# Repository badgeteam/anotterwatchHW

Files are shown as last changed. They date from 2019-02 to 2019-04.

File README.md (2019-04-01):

# AnOtter_Watch

ESP32 driven smart watch with 14-Bit, 2 MSPS Dual Channel scope and component tester.

Back AnOtter_Watch back

[Schematics](/schematics_V1.1/anotterwatch.pdf) read more on the [Wiki](https://wiki.badge.team/AnOtter_Watch)

Designed in KiCad

## Current project status

Prototype d0a3733 ordered

[Gerber files](/gerber_V1.0.zip)

Front AnOtter_Watch front

## V1.1

# Errors

 - [ ] ESP-Pico-D4 foorpint
 - [ ] Display cutout
 - [ ] TCA9535 GND level is ~0.5V when USB is unplugged
 - [ ] WS2812 leds are not working when USB is plugged
 - [ ] Button down can only be pressed when the battery is connected
 
# Tested
  
  - PMIC
  - Charging
  - WS2812
  - Display
  - I2C switch
  - USB-Plug
  - CH341C
  - Button

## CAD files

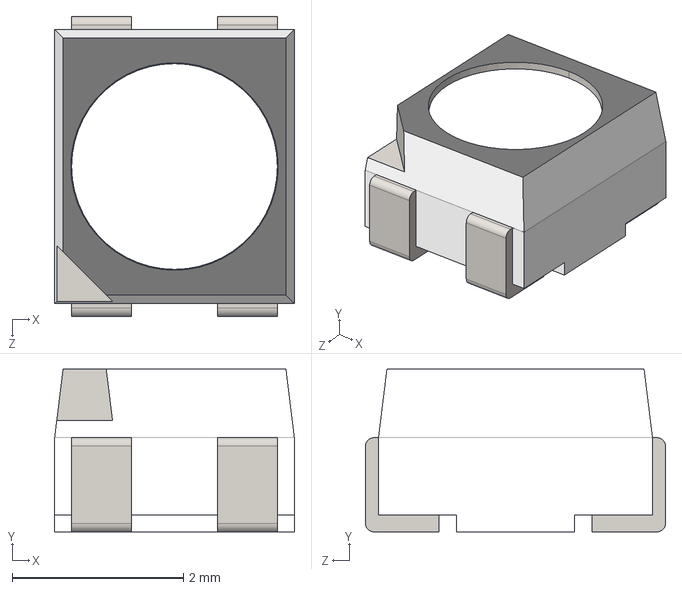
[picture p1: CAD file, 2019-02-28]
3D_models/User Library-ASMB-MTB0-0A3A2.step
2.80 x 1.90 x 3.50 mm

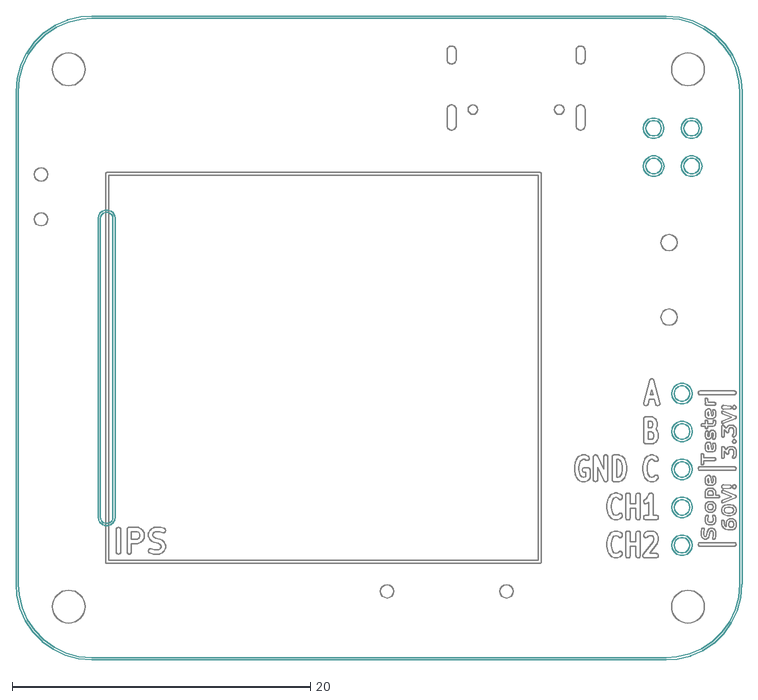
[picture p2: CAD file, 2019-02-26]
anotterwatch_art.dxf
48.7 x 43.2

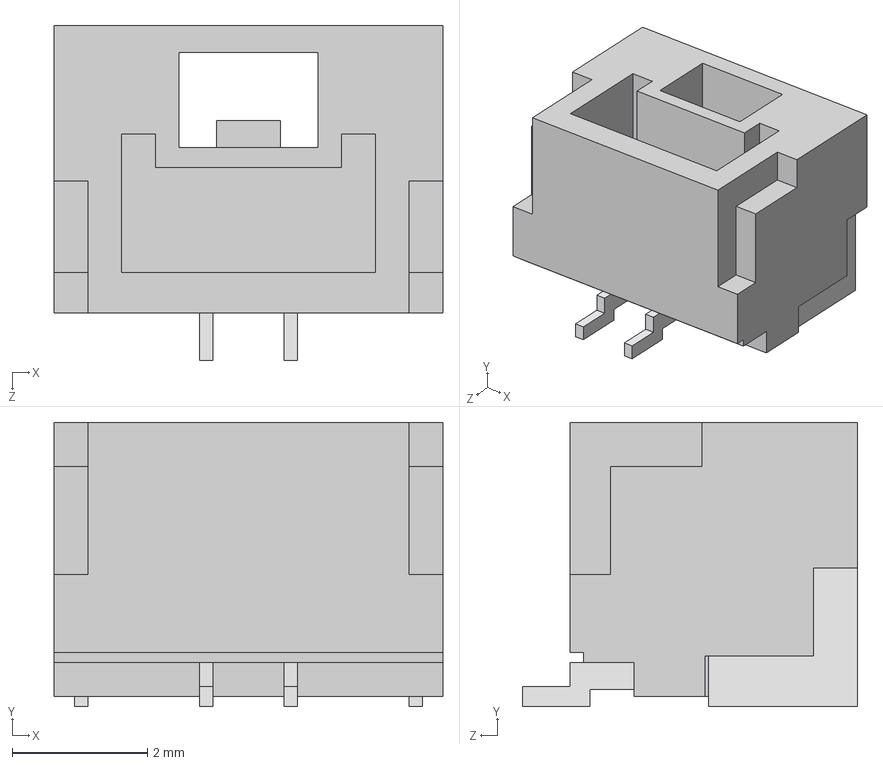
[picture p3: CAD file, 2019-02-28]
3D_models/BM02B-GHS-TBT.STEP
5.75 x 4.20 x 4.95 mm

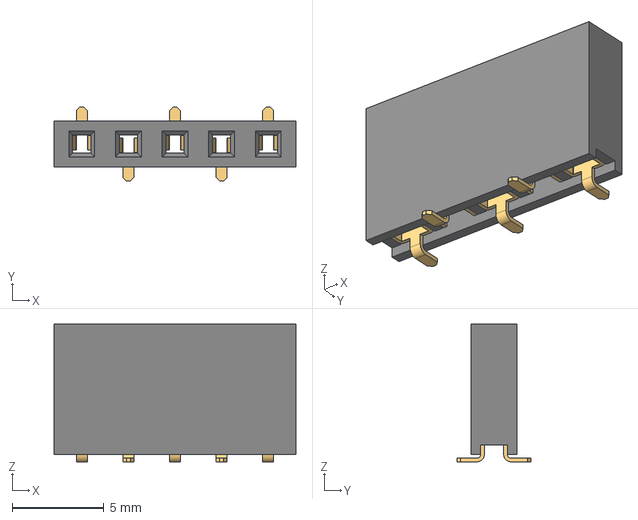
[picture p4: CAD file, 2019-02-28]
3D_models/61000511921 (rev1).stp
13.2 x 4.05 x 7.51 mm
6100051xx21
6100xx1xx21_PIN x 5

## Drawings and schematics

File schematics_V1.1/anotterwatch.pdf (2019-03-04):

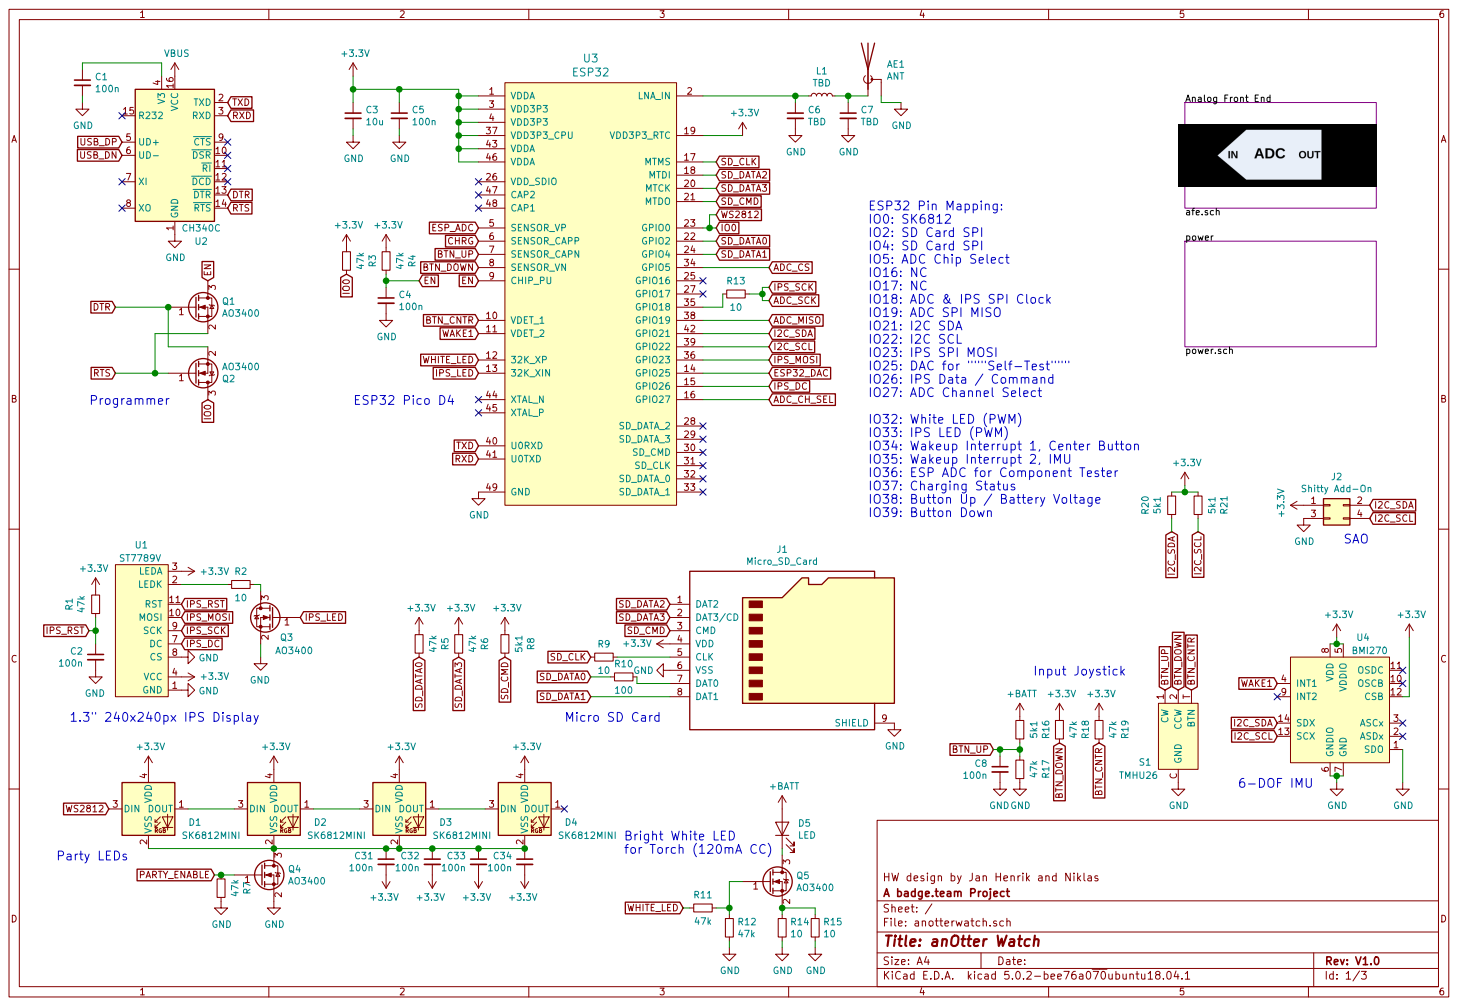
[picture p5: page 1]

1 DSR 10 RI 11 DCD 12 DTR 13 RTS 14 R232 15 VCC 16 TXD 2 RXD 3 V3

4 UD+ 5 UD- 6 XI 7 XO 8 CTS 9 U2 CH340C GND

ESP32 Pin Mapping:
IO2: SD Card SPI
IO4: SD Card SPI
IO5: ADC Chip Select
IO18: ADC & IPS SPI Clock
IO19: ADC SPI MISO
IO21: I2C SDA
IO22: I2C SCL
IO23: IPS SPI MOSI
IO25: DAC for """Self-Test"""
IO26: IPS Data / Command
IO27: ADC Channel Select
IO32: White LED (PWM)
IO33: IPS LED (PWM)
IO34: Wakeup Interrupt 1, Center Button
IO35: Wakeup Interrupt 2, IMU
IO36: ESP ADC for Component Tester
IO37: Charging Status
IO38: Button Up / Battery Voltage

HW design by Jan Henrik and Niklas D5

File: anotterwatch.sch Sheet: / A badge.team Project

Id: 1/3 Title: anOtter Watch

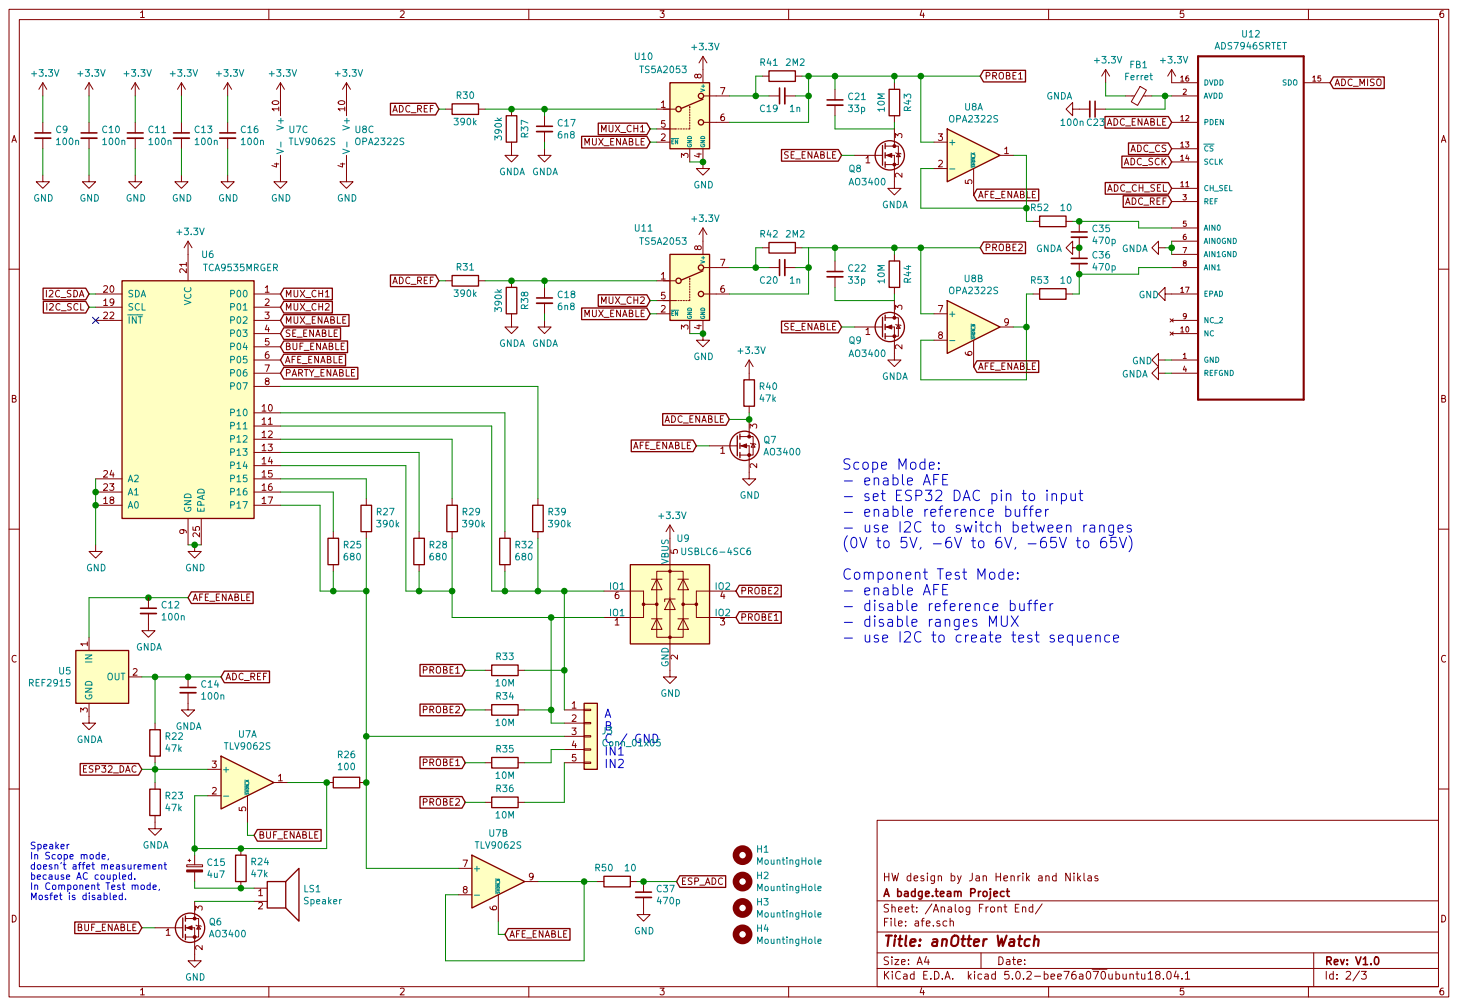
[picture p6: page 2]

- enable AFE
- set ESP32 DAC pin to input
- enable reference buffer
- use I2C to switch between ranges
Component Test Mode:
- disable reference buffer
- disable ranges MUX
- use I2C to create test sequence

47k Speaker
In Scope mode, doesn't affet measurement because AC coupled.

HW design by Jan Henrik and Niklas
A badge.team Project
File: afe.sch Sheet: /Analog Front End/
Id: 2/3 Title: anOtter Watch

In Component Test mode, Mosfet is disabled.

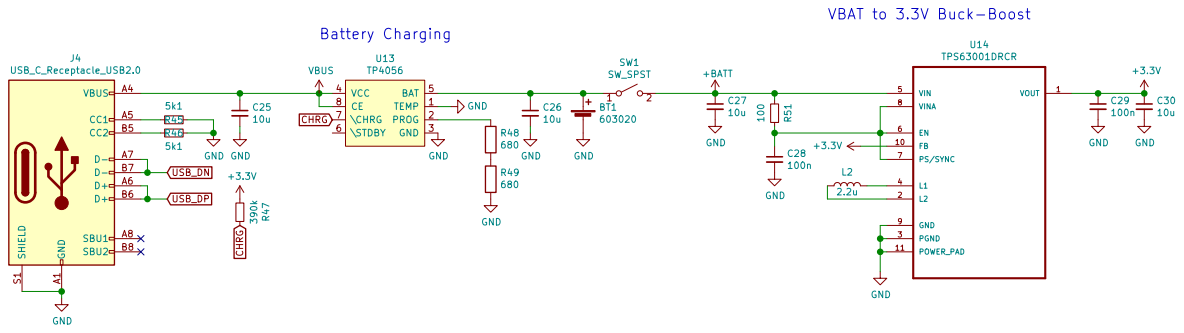
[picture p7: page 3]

A badge.team Project
Sheet: /power/
File: power.sch
Id: 3/3 Title: anOtter Watch

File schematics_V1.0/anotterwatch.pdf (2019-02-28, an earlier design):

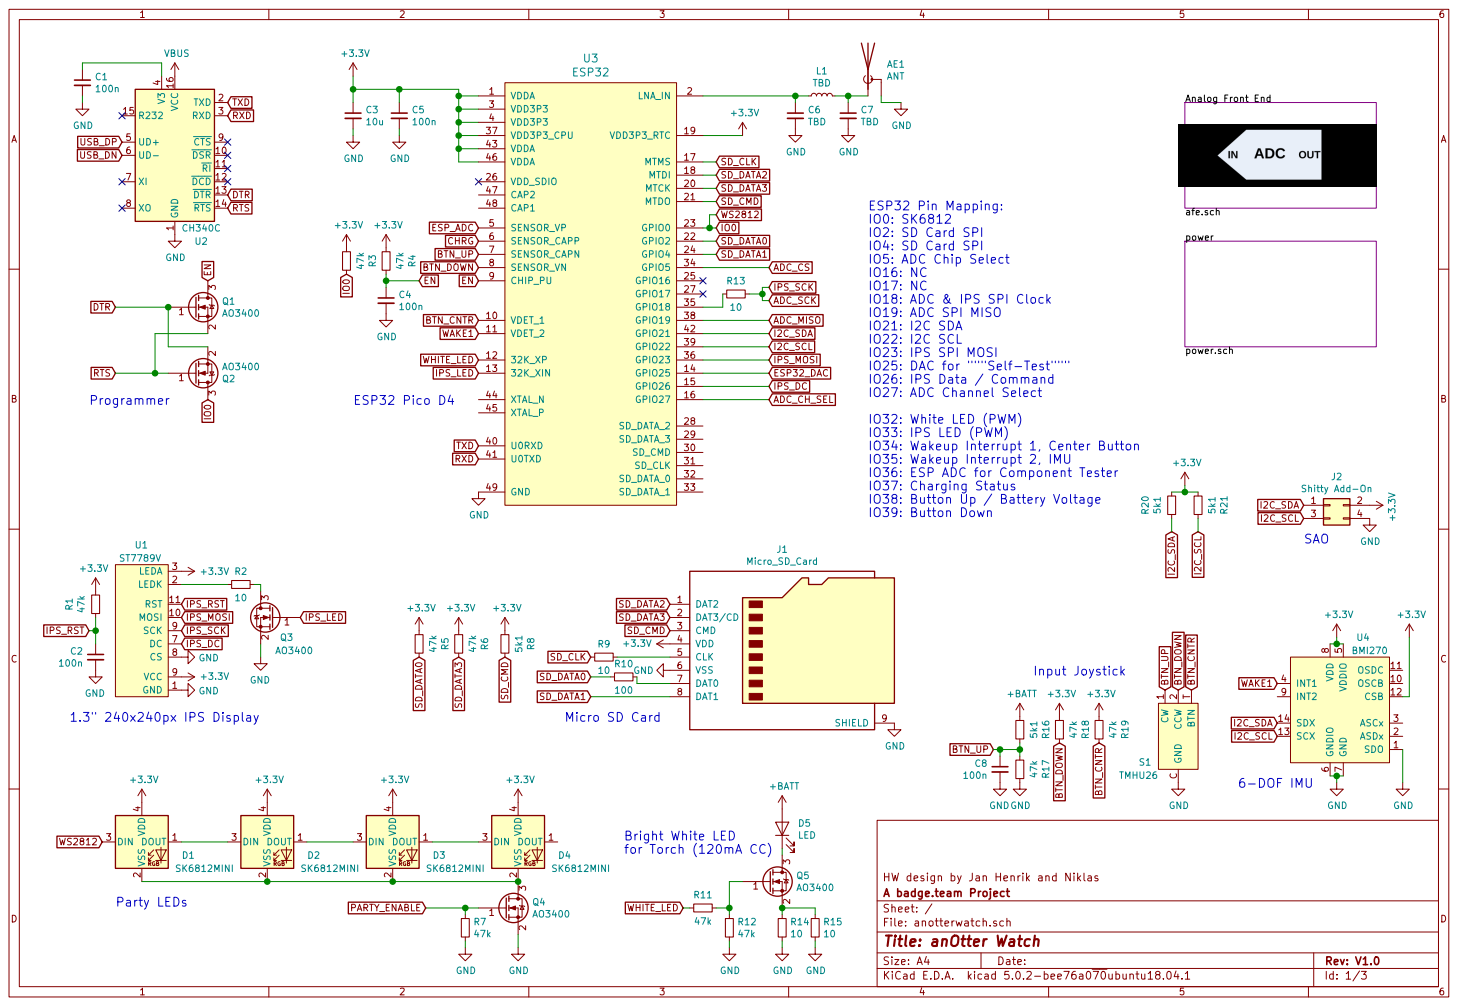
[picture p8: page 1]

1 DSR 10 RI 11 DCD 12 DTR 13 RTS 14 R232 15 VCC 16 TXD 2 RXD 3 V3

4 UD+ 5 UD- 6 XI 7 XO 8 CTS 9 U2 CH340C GND

ESP32 Pin Mapping:
IO2: SD Card SPI
IO4: SD Card SPI
IO5: ADC Chip Select
IO18: ADC & IPS SPI Clock
IO19: ADC SPI MISO
IO21: I2C SDA
IO22: I2C SCL
IO23: IPS SPI MOSI
IO25: DAC for """Self-Test"""
IO26: IPS Data / Command
IO27: ADC Channel Select
IO32: White LED (PWM)
IO33: IPS LED (PWM)
IO34: Wakeup Interrupt 1, Center Button
IO35: Wakeup Interrupt 2, IMU
IO36: ESP ADC for Component Tester
IO37: Charging Status
IO38: Button Up / Battery Voltage

HW design by Jan Henrik and Niklas D5

File: anotterwatch.sch Sheet: / A badge.team Project

Id: 1/3 Title: anOtter Watch

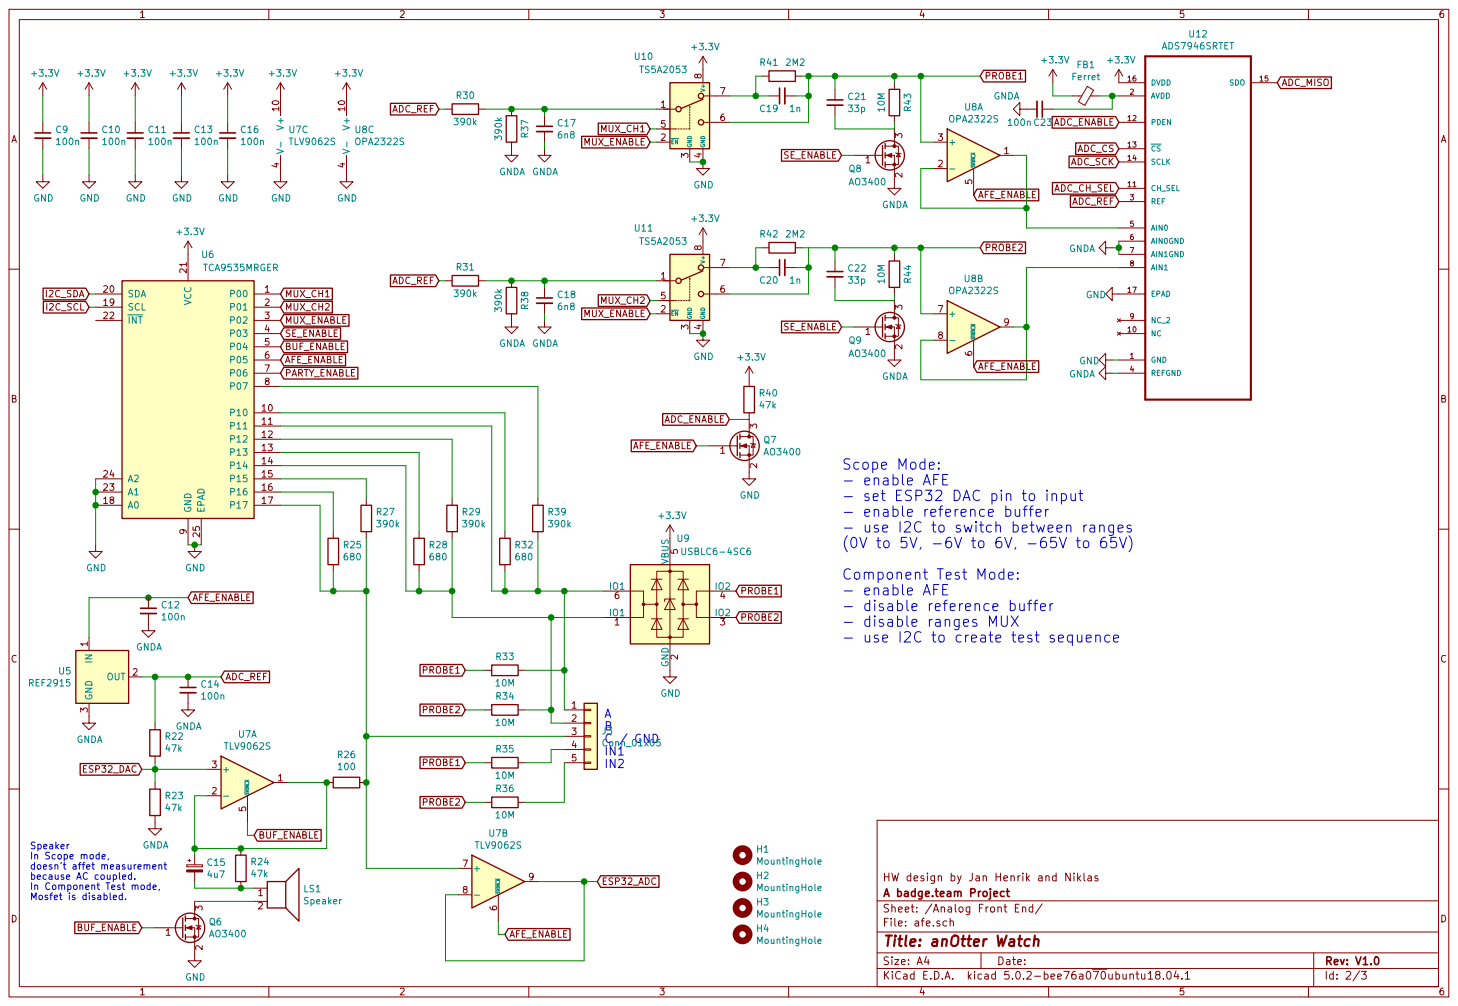
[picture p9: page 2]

- enable AFE
- set ESP32 DAC pin to input
- enable reference buffer
- use I2C to switch between ranges
Component Test Mode:
- disable reference buffer
- disable ranges MUX
- use I2C to create test sequence

47k Speaker
In Scope mode, doesn't affet measurement because AC coupled.

HW design by Jan Henrik and Niklas
A badge.team Project
File: afe.sch Sheet: /Analog Front End/
Id: 2/3 Title: anOtter Watch

In Component Test mode, Mosfet is disabled.

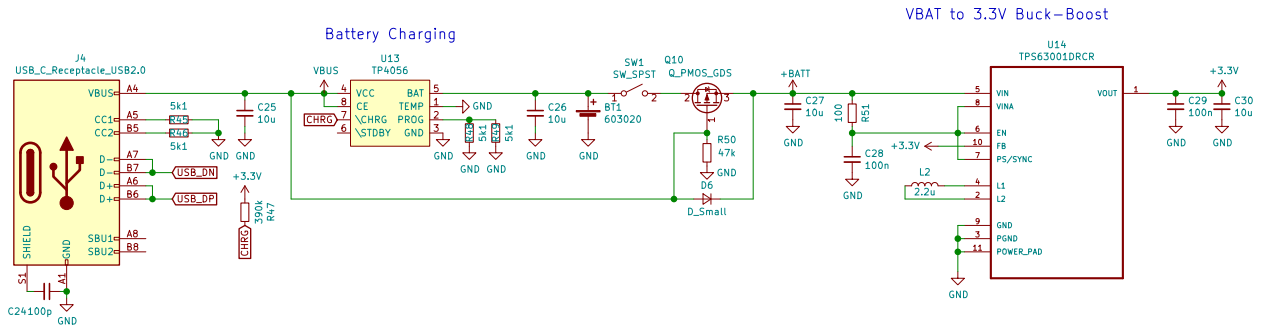
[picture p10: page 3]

A badge.team Project
Sheet: /power/
File: power.sch
Id: 3/3 Title: anOtter Watch

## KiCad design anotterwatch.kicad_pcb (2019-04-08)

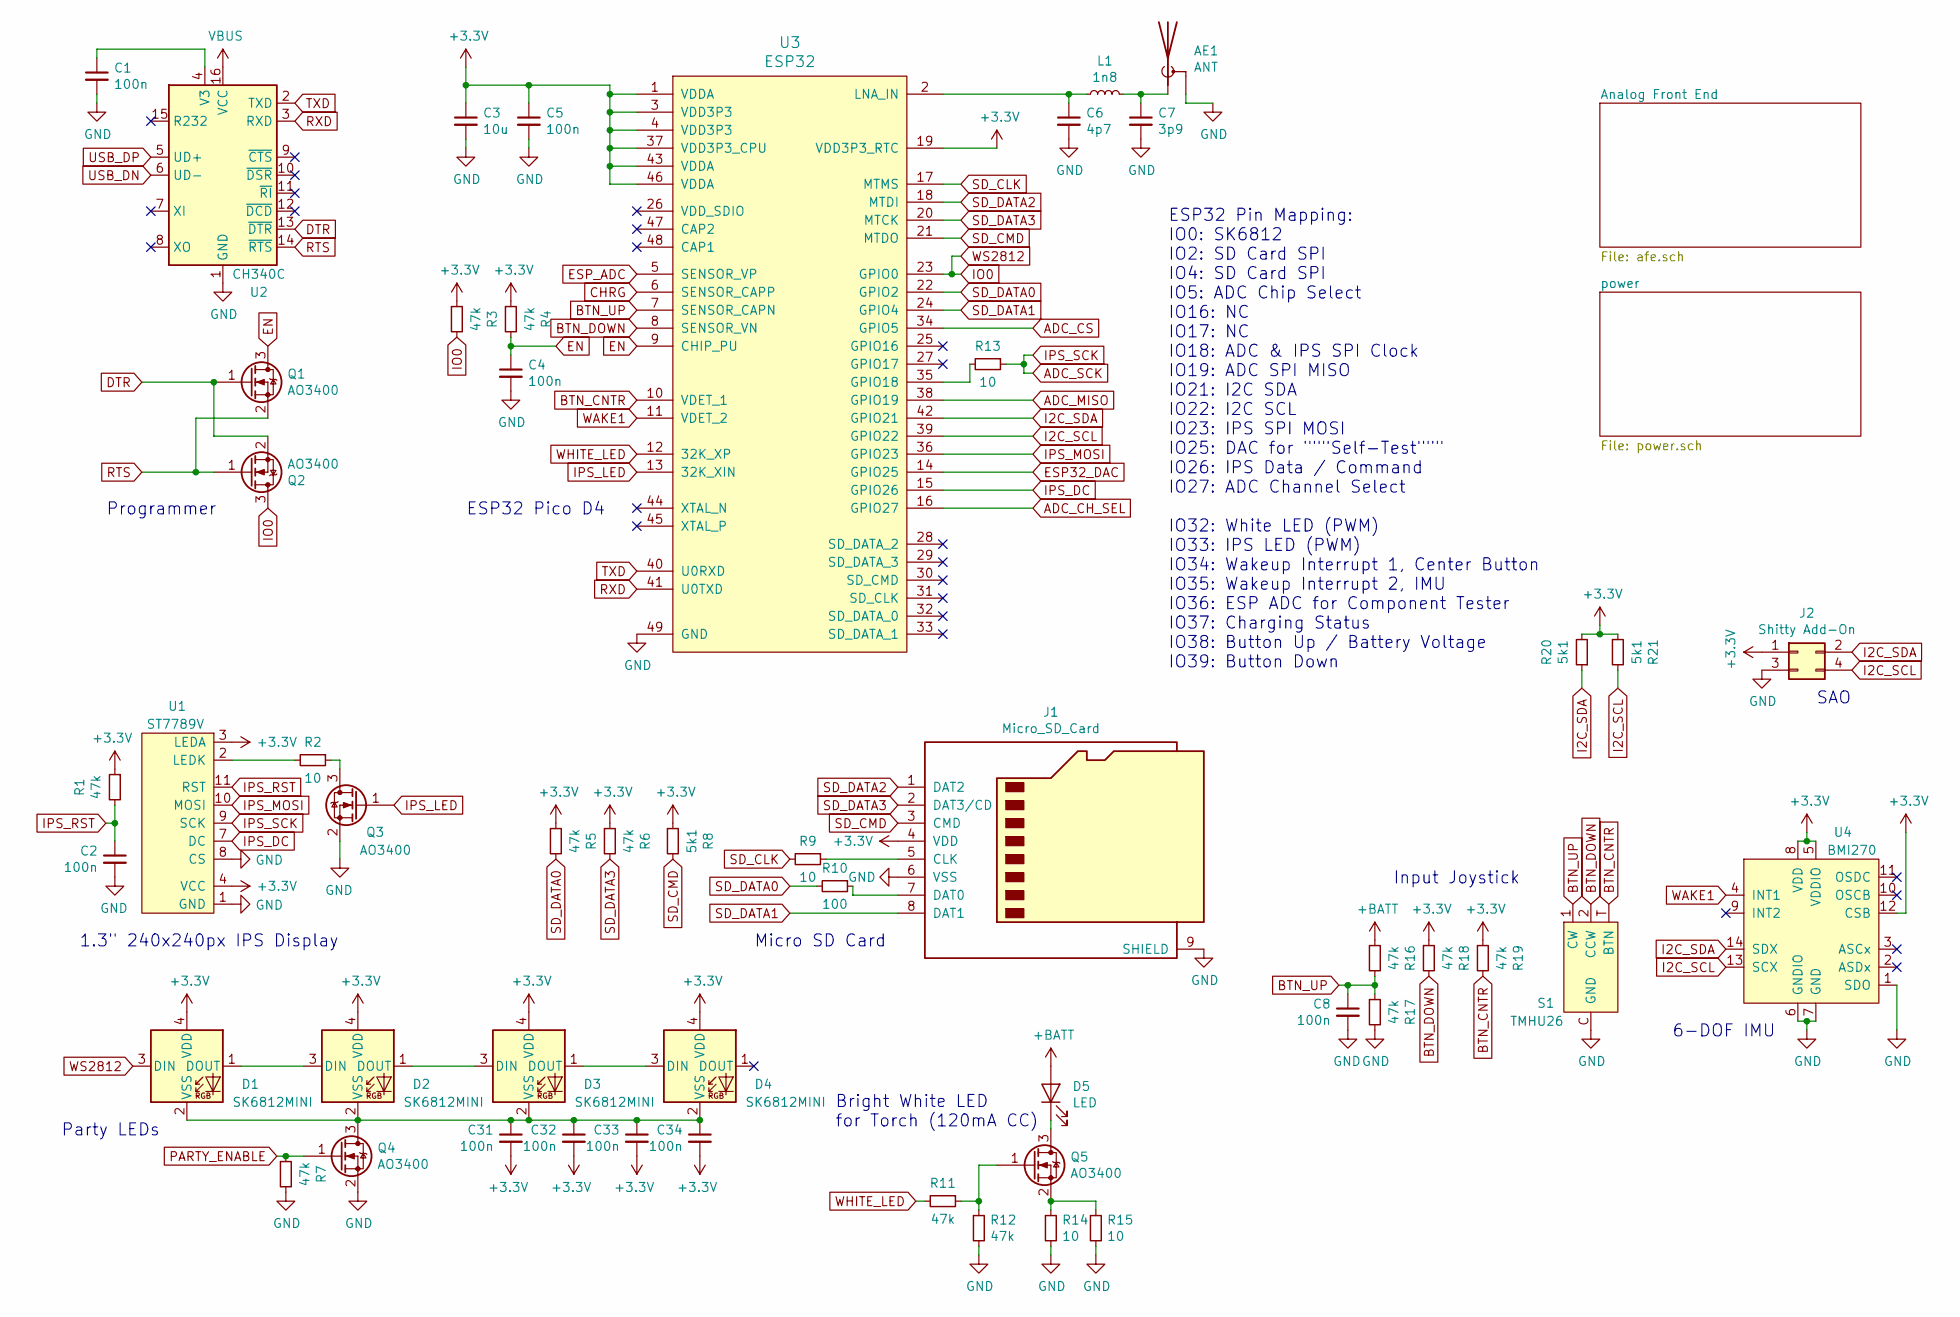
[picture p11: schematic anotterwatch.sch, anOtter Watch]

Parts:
AE1: ANT; Texas_SWRA117D_2.4GHz_Left
C1, C2, C4, C5, C8, C31, C32, C33, C34: 100n; C_0402_1005Metric
C3: 10u; C_0603_1608Metric
C6: 4p7; C_0402_1005Metric
C7: 3p9; C_0402_1005Metric
D1, D2, D3, D4: SK6812MINI; LED_SK6812MINI_PLCC4_3.5x3.5mm_P1.75mm
D5: LED; RZX-S020CCW-0.4T
J1: Micro_SD_Card; SUNTECH_ST-TF-003A
J2: Shitty Add-On; PinSocket_2x02_P2.54mm_Vertical_SMD
L1: 1n8; L_0603_1608Metric
Q1, Q2, Q3, Q4, Q5: AO3400; SOT-23
R1, R3, R4, R5, R6, R7, R11, R12, R16, R17, R18, R19: 47k; R_0402_1005Metric
R2, R9, R13, R14, R15: 10; R_0603_1608Metric
R8, R20, R21: 5k1; R_0402_1005Metric
R10: 100; R_0402_1005Metric
S1: TMHU26
U1: ST7789V
U2: CH340C; SOIC-16_3.9x9.9mm_P1.27mm
U3: ESP32; QFN-48-1EP_7x7mm_P0.5mm_EP5.3x5.3mm
U4: BMI270

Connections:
+3V3: C3.1, C5.1, C31.2, C32.2, C33.2, C34.2, D1.4 (VDD), D2.4 (VDD), D3.4 (VDD), D4.4 (VDD), J1.4 (VDD), J2.1, R1.1, R3.1, R4.1, R5.1, R6.1, R8.1, R18.1, R19.1, R20.2, R21.1, U1.3 (LEDA), U1.4 (VCC), U3.1 (VDDA), U3.3 (VDD3P3), U3.4 (VDD3P3), U3.19 (VDD3P3_RTC), U3.37 (VDD3P3_CPU), U3.43 (VDDA), U3.46 (VDDA), U4.5 (VDDIO), U4.8 (VDD), U4.12 (CSB); also elsewhere on the board
ADC_CH_SEL: U3.16 (GPIO27); also elsewhere on the board
ADC_CS: U3.34 (GPIO5); also elsewhere on the board
ADC_MISO: U3.38 (GPIO19); also elsewhere on the board
ADC_SCK: R13.1, U1.9 (SCK); also elsewhere on the board
BTN_CNTR: R19.2, S1.T (BTN), U3.10 (VDET_1)
BTN_DOWN: R18.2, S1.2 (CCW), U3.8 (SENSOR_VN)
BTN_UP: C8.1, R16.2, R17.1, S1.1 (CW), U3.7 (SENSOR_CAPN)
CHRG: U3.6 (SENSOR_CAPP); also elsewhere on the board
DTR: Q1.1 (G), Q2.2 (S), U2.13 (~DTR)
EN: C4.1, Q1.3 (D), R4.2, U3.9 (CHIP_PU)
ESP32_DAC: U3.14 (GPIO25); also elsewhere on the board
ESP_ADC: U3.5 (SENSOR_VP); also elsewhere on the board
GND: AE1.2 (Shield), C1.2, C2.2, C3.2, C4.2, C5.2, C6.2, C7.2, C8.2, J1.6 (VSS), J1.9 (SHIELD), J2.3, Q3.2 (S), Q4.2 (S), R7.2, R12.2, R14.2, R15.2, R17.2, S1.C (GND), U1.1 (GND), U1.5 (GND), U1.6 (GND), U1.8 (CS), U1.12, U2.1 (GND), U3.49 (GND), U4.1 (SDO), U4.6 (GNDIO), U4.7 (GND); also elsewhere on the board
I2C_SCL: J2.4, R21.2, U3.39 (GPIO22), U4.13 (SCX); also elsewhere on the board
I2C_SDA: J2.2, R20.1, U3.42 (GPIO21), U4.14 (SDX); also elsewhere on the board
IO0: D1.3 (DIN), Q2.3 (D), R3.2, U3.23 (GPIO0)
IPS_DC: U1.7 (DC), U3.15 (GPIO26)
IPS_LED: Q3.1 (G), U3.13 (32K_XIN)
IPS_MOSI: U1.10 (MOSI), U3.36 (GPIO23)
IPS_RST: C2.1, R1.2, U1.11 (RST)
unnamed: AE1.1 (A), C7.1, L1.2
unnamed: C1.1, U2.4 (V3)
unnamed: C6.1, L1.1, U3.2 (LNA_IN)
unnamed: C31.1, C32.1, C33.1, C34.1, D1.2 (VSS), D2.2 (VSS), D3.2 (VSS), D4.2 (VSS), Q4.3 (D)
unnamed: D1.1 (DOUT), D2.3 (DIN)
unnamed: D2.1 (DOUT), D3.3 (DIN)
unnamed: D3.1 (DOUT), D4.3 (DIN)
unnamed: J1.5 (CLK), R9.1
unnamed: J1.7 (DAT0), R10.1
unnamed: Q3.3 (D), R2.1
unnamed: Q5.1 (G), R11.1, R12.1
unnamed: Q5.2 (S), R14.1, R15.1
unnamed: R2.2, U1.2 (LEDK)
unnamed: R13.2, U3.35 (GPIO18)
PARTY_ENABLE: Q4.1 (G), R7.1; also elsewhere on the board
RTS: Q1.2 (S), Q2.1 (G), U2.14 (~RTS)
RXD: U2.3 (RXD), U3.41 (U0TXD)
SD_CLK: R9.2, U3.17 (MTMS)
SD_CMD: J1.3 (CMD), R8.2, U3.21 (MTDO)
SD_DATA0: R5.2, R10.2, U3.22 (GPIO2)
SD_DATA1: J1.8 (DAT1), U3.24 (GPIO4)
SD_DATA2: J1.1 (DAT2), U3.18 (MTDI)
SD_DATA3: J1.2 (DAT3/CD), R6.2, U3.20 (MTCK)
TXD: U2.2 (TXD), U3.40 (U0RXD)
USB_DN: U2.6 (UD-); also elsewhere on the board
USB_DP: U2.5 (UD+); also elsewhere on the board
VBUS: U2.16 (VCC); also elsewhere on the board
WAKE1: U3.11 (VDET_2), U4.4 (INT1)
WHITE_LED: R11.2, U3.12 (32K_XP)

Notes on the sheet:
ESP32 Pin Mapping: IO0: SK6812 IO2: SD Card SPI IO4: SD Card SPI IO5: ADC Chip Select IO16: NC IO17: NC IO18: ADC & IPS SPI Clock IO19: ADC SPI MISO IO21: I2C SDA IO22: I2C SCL IO23: IPS SPI MOSI IO25: DAC for """Self-Test""" IO26: IPS Data / Command IO27: ADC Channel Select IO32: White LED (PWM) I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
Programmer
1.3" 240x240px IPS Display
Party LEDs
Bright White LED for Torch (120mA CC)
Micro SD Card
Input Joystick
6-DOF IMU
SAO
ESP32 Pico D4

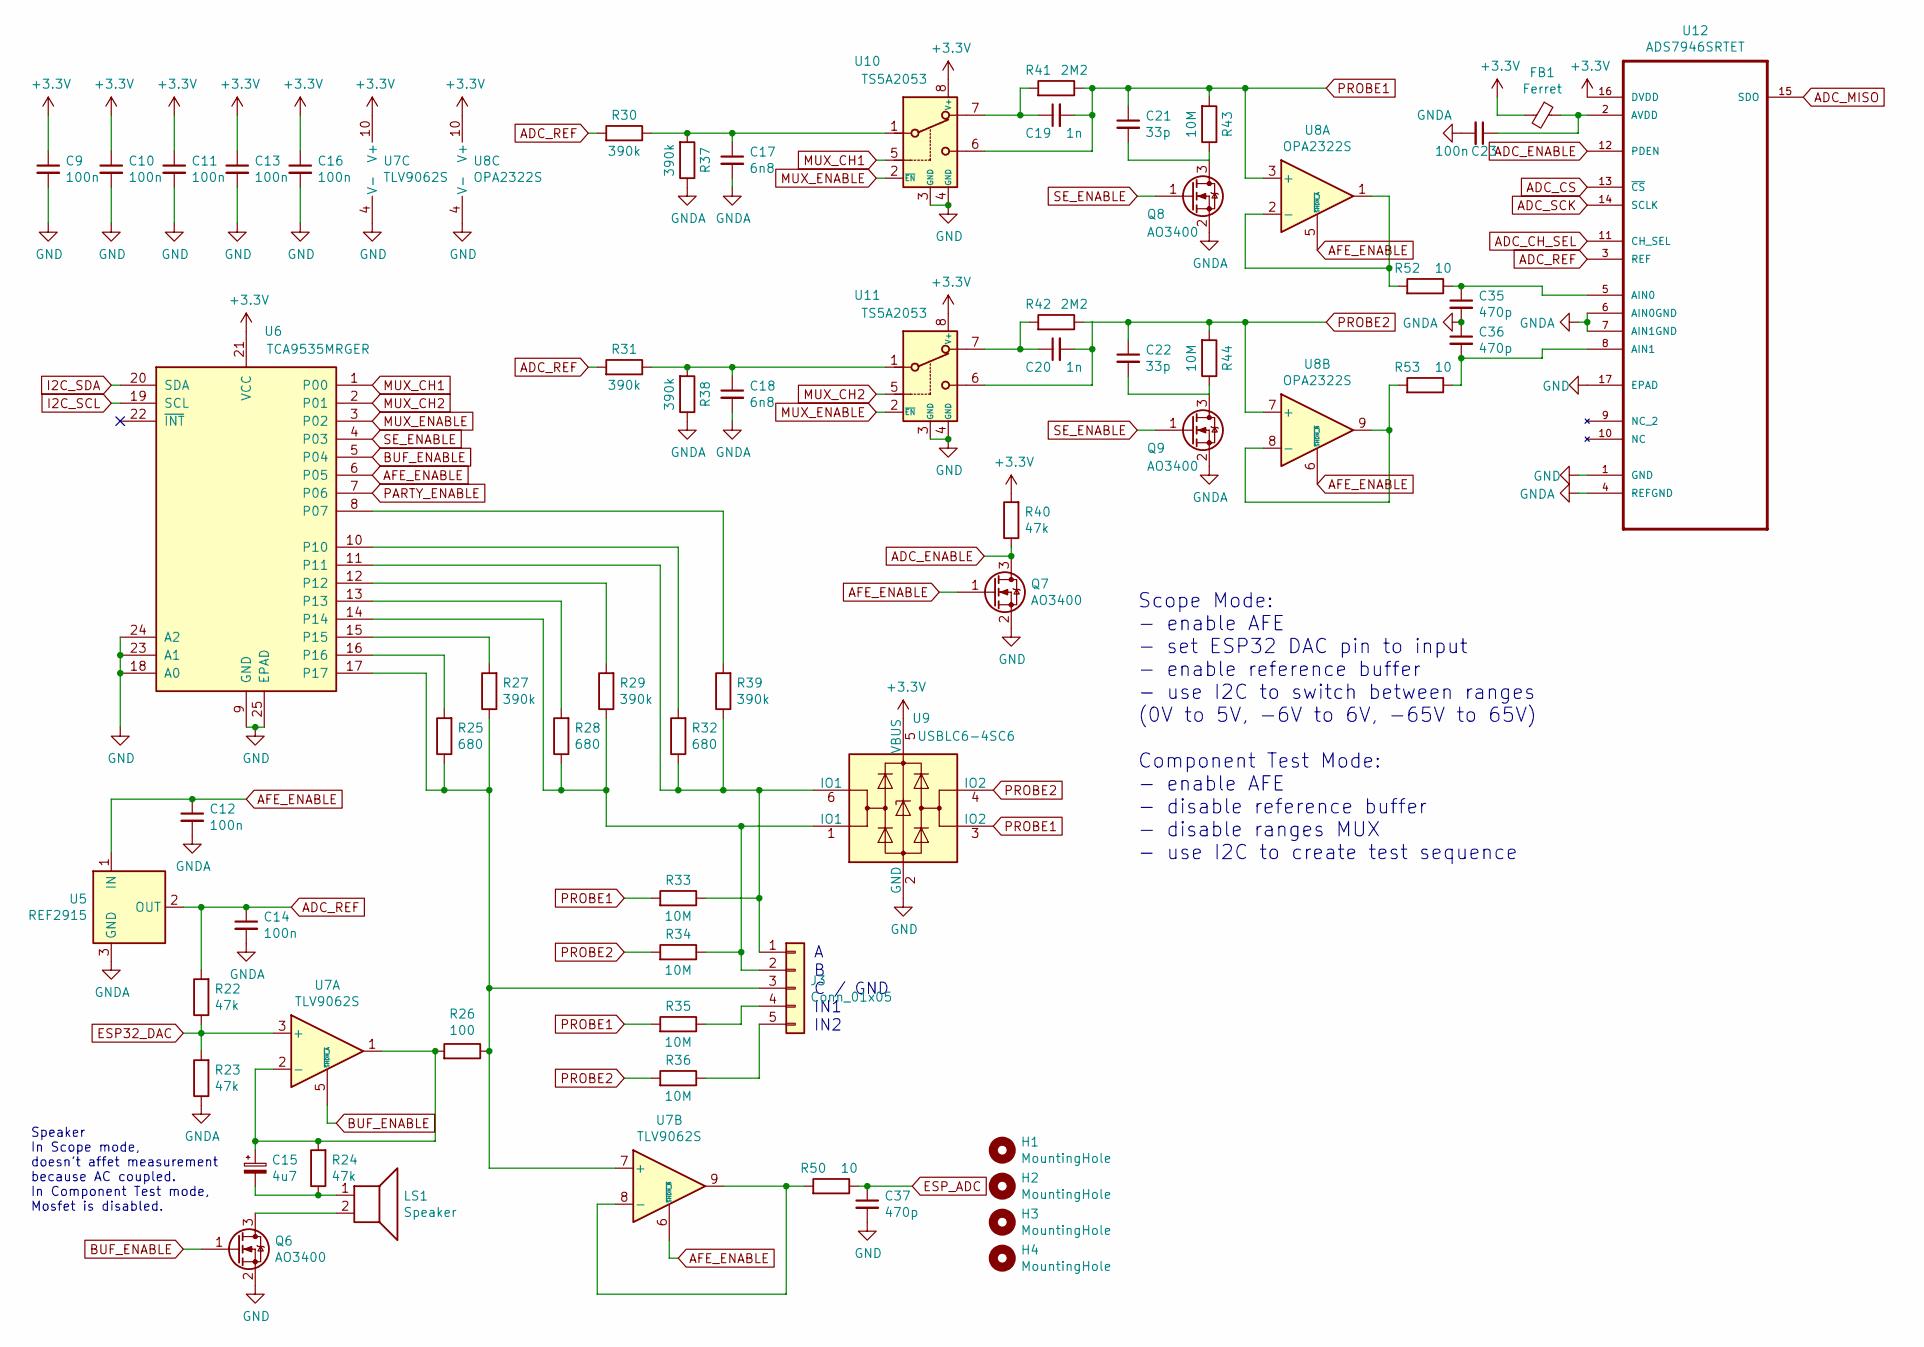
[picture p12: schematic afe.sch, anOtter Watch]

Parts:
C9, C10, C11, C12, C13, C14, C16: 100n; C_0402_1005Metric
C15: 4u7; C_0603_1608Metric
C17, C18: 6n8; C_0402_1005Metric
C19, C20: 1n; C_0402_1005Metric
C21, C22: 33p; C_0402_1005Metric
C23: 100n; C_0603_1608Metric
C35, C36, C37: 470p; C_0402_1005Metric
FB1: Ferret; L_0603_1608Metric
H1, H2, H3, H4: MountingHole; MountingHole_2.2mm_M2
J3: Conn_01x05; PinHeader_1x05_P2.54mm_Vertical_SMD_Pin1Left
LS1: Speaker; Molex_KK-254_AE-6410-02A_1x02_P2.54mm_Vertical
Q6, Q7, Q8, Q9: AO3400; SOT-23
R22, R23, R24, R40: 47k; R_0402_1005Metric
R25, R28, R32: 680; R_0402_1005Metric
R26: 100; R_0402_1005Metric
R27, R29, R30, R31, R37, R38, R39: 390k; R_0402_1005Metric
R33, R34, R35, R36: 10M; R_0603_1608Metric
R41, R42: 2M2; R_0402_1005Metric
R43, R44: 10M; R_0402_1005Metric
R50, R52, R53: 10; R_0603_1608Metric
U5: REF2915; SOT-23
U6: TCA9535MRGER; QFN-24-1EP_4x4mm_P0.5mm_EP2.6x2.6mm
U7: TLV9062S; VSSOP-10
U8: OPA2322S; VSSOP-10
U9: USBLC6-4SC6; SOT-23-6
U10, U11: TS5A2053; VSSOP-8_2.4x2.1mm_P0.5mm
U12: ADS7946SRTET; QFN-16-1EP_3x3mm_P0.5mm_EP1.8x1.8mm

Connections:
+3V3: C9.1, C10.1, C11.1, C13.1, C16.1, FB1.2, R40.2, U6.21 (VCC), U7.10 (V+), U8.10 (V+), U9.5 (VBUS), U10.8 (V+), U11.8 (V+), U12.16 (DVDD); also elsewhere on the board
ADC_CH_SEL: U12.11 (CH_SEL); also elsewhere on the board
ADC_CS: U12.13 (~CS~); also elsewhere on the board
ADC_ENABLE: Q7.3 (D), R40.1, U12.12 (PDEN)
ADC_MISO: U12.15 (SDO); also elsewhere on the board
ADC_REF: C14.1, R22.2, R30.2, R31.2, U5.2 (OUT), U12.3 (REF)
ADC_SCK: U12.14 (SCLK); also elsewhere on the board
AFE_ENABLE: C12.1, Q7.1 (G), U5.1 (IN), U6.6 (P05), U7.6 (~SHDN_B), U8.5 (~SHDN_A), U8.6 (~SHDN_B)
BUF_ENABLE: Q6.1 (G), U6.5 (P04), U7.5 (~SHDN_A)
ESP32_DAC: R22.1, R23.2, U7.3 (+); also elsewhere on the board
ESP_ADC: C37.1, R50.1; also elsewhere on the board
GND: C9.2, C10.2, C11.2, C13.2, C16.2, C37.2, Q6.2 (S), Q7.2 (S), U6.9 (GND), U6.18 (A0), U6.23 (A1), U6.24 (A2), U6.25 (EPAD), U7.4 (V-), U7.11 (V-), U8.4 (V-), U8.11 (V-), U9.2 (GND), U10.3 (GND), U10.4 (GND), U11.3 (GND), U11.4 (GND), U12.1 (GND), U12.17 (EPAD); also elsewhere on the board
GNDA: C12.2, C14.2, C17.2, C18.2, C23.2, C35.2, C36.1, Q8.2 (S), Q9.2 (S), R23.1, R37.1, R38.1, U5.3 (GND), U12.4 (REFGND), U12.6 (AIN0GND), U12.7 (AIN1GND)
I2C_SCL: U6.19 (SCL); also elsewhere on the board
I2C_SDA: U6.20 (SDA); also elsewhere on the board
MUX_CH1: U6.1 (P00), U10.5
MUX_CH2: U6.2 (P01), U11.5
MUX_ENABLE: U6.3 (P02), U10.2 (~EN), U11.2 (~EN)
unnamed: C15.1, R24.2, R26.2, U7.1, U7.2 (-)
unnamed: C15.2, LS1.1, R24.1
unnamed: C17.1, R30.1, R37.2, U10.1
unnamed: C18.1, R31.1, R38.2, U11.1
unnamed: C19.1, R41.2, U10.7
unnamed: C20.1, R42.2, U11.7
unnamed: C21.2, Q8.3 (D), R43.1
unnamed: C22.2, Q9.3 (D), R44.1
unnamed: C23.1, FB1.1, U12.2 (AVDD)
unnamed: C35.1, R52.1, U12.5 (AIN0)
unnamed: C36.2, R53.1, U12.8 (AIN1)
unnamed: J3.1, R32.1, R33.1, R39.1, U6.11, U9.6 (IO1)
unnamed: J3.2, R28.1, R29.1, R34.1, U6.14, U9.1 (IO1)
unnamed: J3.3, R25.1, R26.1, R27.1, U6.17, U7.7 (+)
unnamed: J3.4, R35.1
unnamed: J3.5, R36.1
unnamed: LS1.2, Q6.3 (D)
unnamed: R25.2, U6.16
unnamed: R27.2, U6.15
unnamed: R28.2, U6.13
unnamed: R29.2, U6.12
unnamed: R32.2, U6.10
unnamed: R39.2, U6.8 (P07)
unnamed: R50.2, U7.8 (-), U7.9
unnamed: R52.2, U8.1, U8.2 (-)
unnamed: R53.2, U8.8 (-), U8.9
PARTY_ENABLE: U6.7 (P06); also elsewhere on the board
PROBE1: C19.2, C21.1, R33.2, R35.2, R41.1, R43.2, U8.3 (+), U9.3 (IO2), U10.6
PROBE2: C20.2, C22.1, R34.2, R36.2, R42.1, R44.2, U8.7 (+), U9.4 (IO2), U11.6
SE_ENABLE: Q8.1 (G), Q9.1 (G), U6.4 (P03)

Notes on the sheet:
A B C / GND IN1 IN2
Scope Mode: - enable AFE - set ESP32 DAC pin to input - enable reference buffer - use I2C to switch between ranges (0V to 5V, -6V to 6V, -65V to 65V) Component Test Mode: - enable AFE - disable reference buffer - disable ranges MUX - use I2C to create test sequence
Speaker In Scope mode, doesn't affet measurement because AC coupled. In Component Test mode, Mosfet is disabled.

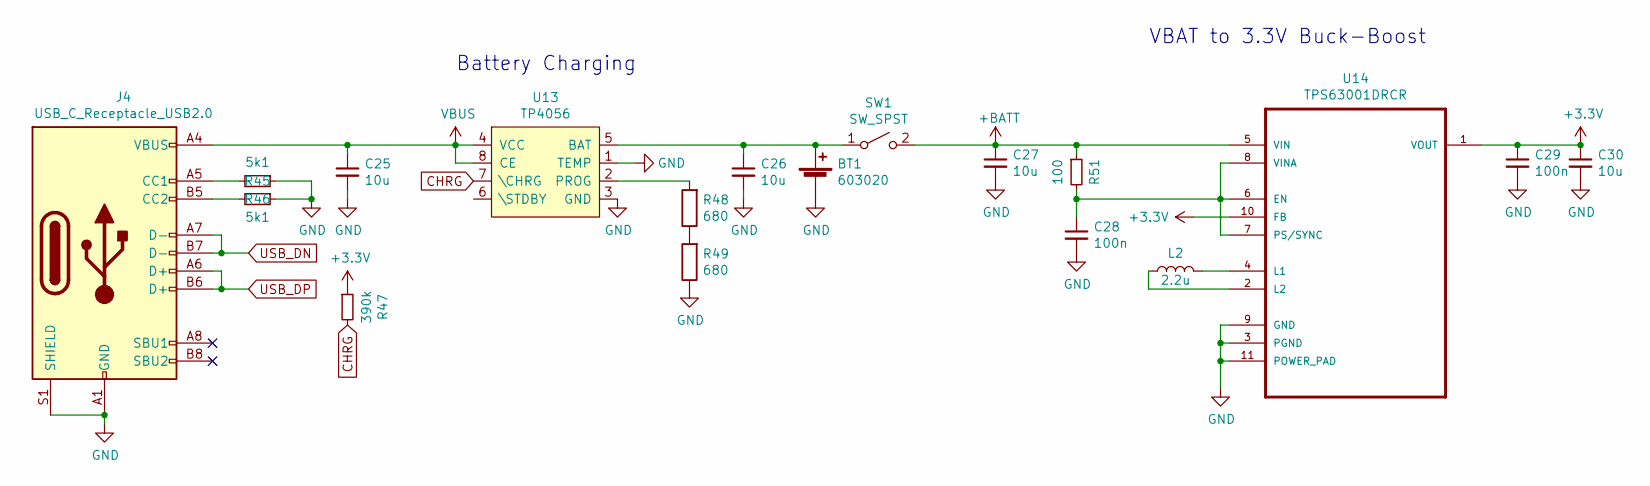
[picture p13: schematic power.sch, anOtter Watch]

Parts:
BT1: 603020; JST_GH_BM02B-GHS-TBT_1x02-1MP_P1.25mm_Vertical
C25, C26, C27, C30: 10u; C_0603_1608Metric
C28, C29: 100n; C_0402_1005Metric
J4: USB_C_Receptacle_USB2.0; USB-C 16Pin
L2: 2.2u; L_Taiyo-Yuden_MD-3030
R45, R46: 5k1; R_0402_1005Metric
R47: 390k; R_0402_1005Metric
R48, R49: 680; R_0402_1005Metric
R51: 100; R_0402_1005Metric
SW1: SW_SPST; SW_SPDT_PCM12
U13: TP4056; Diodes_PSOP-8
U14: TPS63001DRCR; Texas_S-PVSON-N10

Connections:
+3V3: C29.1, C30.1, R47.1, U14.1 (VOUT), U14.10 (FB); also elsewhere on the board
CHRG: R47.2, U13.7 (\CHRG); also elsewhere on the board
GND: BT1.2 (-), C25.2, C26.2, C27.2, C28.2, C29.2, C30.2, J4.A1 (GND), J4.A12 (GND), J4.B1 (GND), J4.B12 (GND), J4.S1 (SHIELD), R45.1, R46.1, R49.1, U13.1 (TEMP), U13.3 (GND), U14.3 (PGND), U14.9 (GND), U14.11 (POWER_PAD); also elsewhere on the board
unnamed: BT1.1 (+), C26.1, SW1.1 (A), U13.5 (BAT)
unnamed: C28.1, R51.2, U14.6 (EN), U14.7 (PS/SYNC), U14.8 (VINA)
unnamed: J4.A5 (CC1), R45.2
unnamed: J4.B5 (CC2), R46.2
unnamed: L2.1, U14.2 (L2)
unnamed: L2.2, U14.4 (L1)
unnamed: R48.1, R49.2
unnamed: R48.2, U13.2 (PROG)
USB_DN: J4.A7 (D-), J4.B7 (D-); also elsewhere on the board
USB_DP: J4.A6 (D+), J4.B6 (D+); also elsewhere on the board
VBUS: C25.1, J4.A4 (VBUS), J4.A9 (VBUS), J4.B4 (VBUS), J4.B9 (VBUS), U13.4 (VCC), U13.8 (CE); also elsewhere on the board

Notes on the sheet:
VBAT to 3.3V Buck-Boost
Battery Charging

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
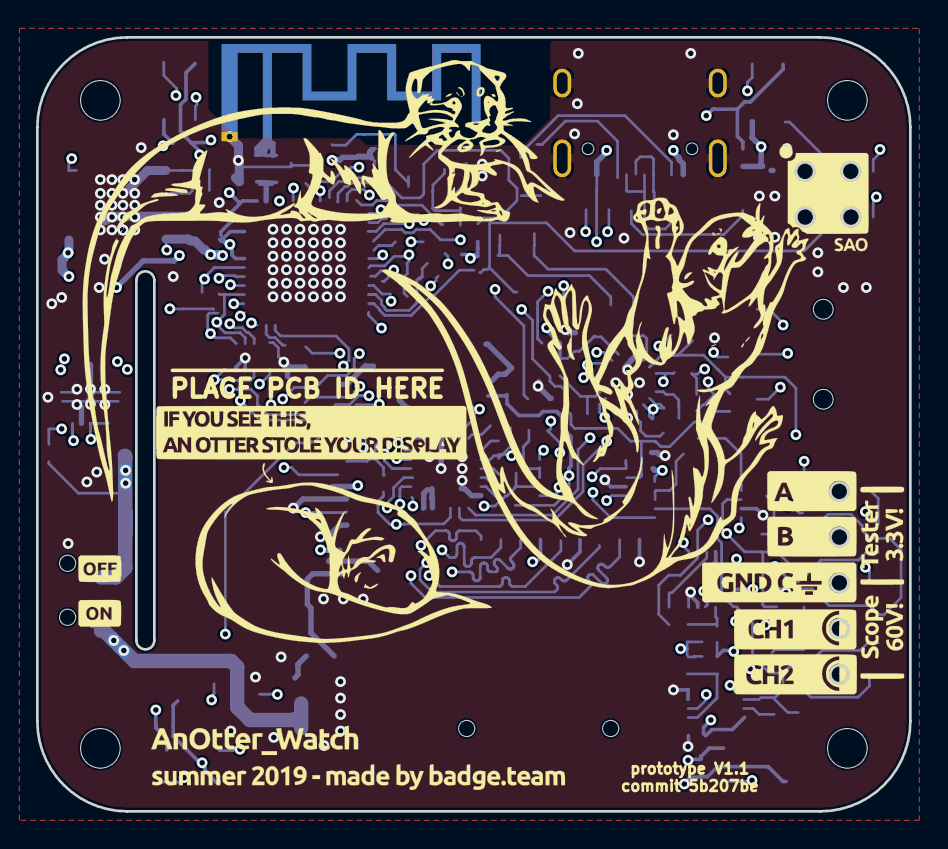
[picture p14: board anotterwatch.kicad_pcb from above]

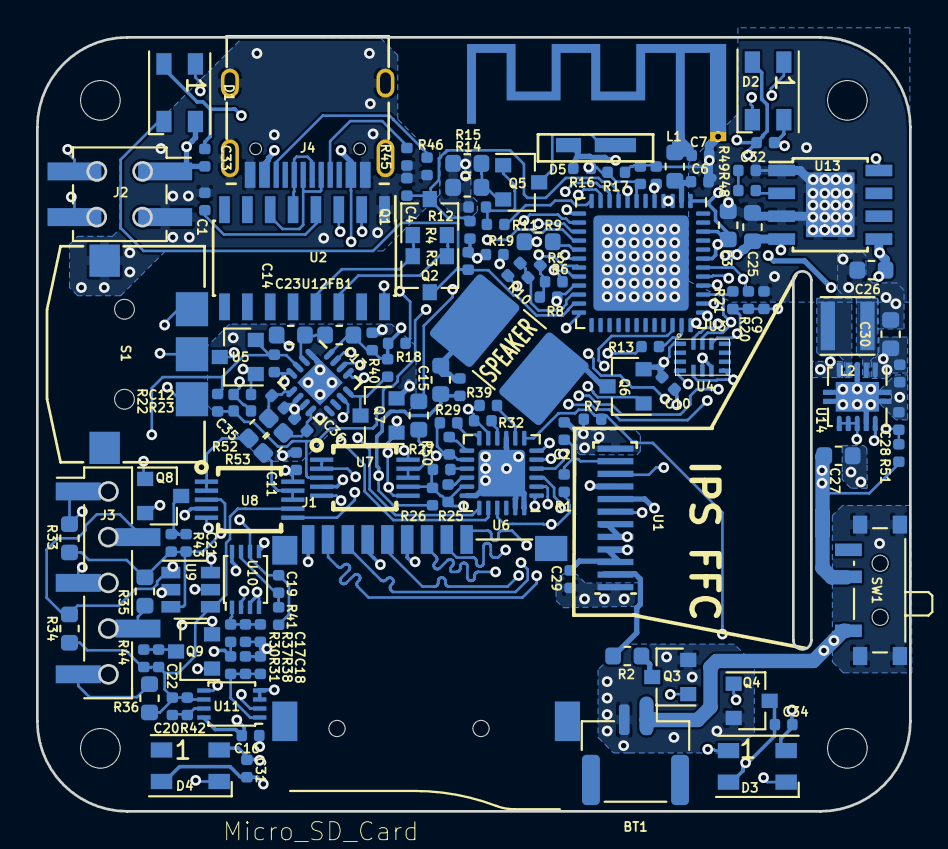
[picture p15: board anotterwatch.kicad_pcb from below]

Board: 4 copper layers, 48.5 x 43.0 mm, 132 parts (128 on the bottom side), 97 nets.

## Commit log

2019-02-20 initial commit #2
    [anotterwatch.kicad_pcb, anotterwatch.sch]
2019-02-20 added USB-C connector
    [anotterwatch.sch]
2019-02-20 created USB-C connector footprint
2019-02-20 added sk6812
    [anotterwatch.sch]
2019-02-20 added led
    [anotterwatch.sch]
2019-02-20 added led footprint
2019-02-20 added datasheets
    [anotterwatch.sch]
2019-02-22 added displays footprint
2019-02-22 fixed lib
    [anotterwatch.sch]
2019-02-22 added display + datasheet, removed VDD added VCC
    [anotterwatch.sch]
2019-02-22 moved LED A and K
2019-02-22 added display footprint
2019-02-23 added reset circuit
    [anotterwatch.sch]
2019-02-23 added esp
    [anotterwatch.sch]
2019-02-23 added datasheet esp
    [anotterwatch.sch]
2019-02-24 Im an Otter
    [anotterwatch.sch]
2019-02-24 Im an Otter #2
    [anotterwatch.sch]
2019-02-24 ADD: Analog Front-End
    [afe.sch, anotterwatch.kicad_pcb, anotterwatch.sch]
2019-02-24 added switch
2019-02-24 ADD: Jog switch
    [anotterwatch.kicad_pcb]
2019-02-24 added switch symbol
2019-02-25 ADD: ESP32 pinout
    [anotterwatch.kicad_pcb, anotterwatch.sch]
2019-02-25 added BMI and TPS
    [anotterwatch.sch]
2019-02-25 *white smoke*
    [afe.sch, anotterwatch.sch]
2019-02-25 ADD: speaker
    [afe.sch, anotterwatch.sch]
2019-02-25 ADD: speaker fet to make it compagtible to component tester mode
    [afe.sch]
2019-02-26 added power schematics
    [Power.sch, anotterwatch.sch]
2019-02-26 Schematic cleanup
    [Power.sch, anotterwatch.sch]
2019-02-26 added power sheet
    [afe.sch]
2019-02-26 added datasheets and descriptions
    [Power.sch, afe.sch, anotterwatch.sch]
2019-02-26 renamed power.sch
    [power.sch]
2019-02-26 add anotation
    [afe.sch, anotterwatch.sch, power.sch]
2019-02-26 added SD Card socket lib
2019-02-26 added SD Card socket footprint
    [anotterwatch.kicad_pcb, anotterwatch.sch]
2019-02-26 added shitty addon todo
    [anotterwatch.sch]
2019-02-26 UPD: finalized schematic, started layout
    [afe.sch, anotterwatch.kicad_pcb, anotterwatch.sch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]
2019-02-26 Finalized front
    [anotterwatch.kicad_pcb, anotterwatch_art.dxf]
2019-02-28 ADD: constant current source for high power LED
    [afe.sch, anotterwatch.sch, power.sch]
2019-02-28 ADD:started to place footprints
    [61000511921 (rev1).stp, BM02B-GHS-TBT.STEP, User Library-ASMB-MTB0-0A3A2.step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]
2019-03-01 ADD: started routing
    [afe.sch, anotterwatch.kicad_pcb, anotterwatch.sch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]
2019-03-01 ADD: tbc
    [anotterwatch.kicad_pcb]
2019-03-01 fixed display footprint
2019-03-01 fixed label and unconnected net
    [afe.sch, anotterwatch.sch]
2019-03-01 added USB-C datasheet
    [power.sch]
2019-03-01 added pwoer layout
    [anotterwatch.kicad_pcb]
2019-03-01 UPD: removed all p-fets, no more ideal diode
    [anotterwatch.sch, power.sch]
2019-03-01 fixed 3D models
    [anotterwatch.kicad_pcb]
2019-03-04 Finished layout
    [afe.sch, anotterwatch.kicad_pcb, anotterwatch.sch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]
2019-03-04 Finished silkscreen
    [anotterwatch.kicad_pcb]
2019-03-04 Final design for first prototype
    [anotterwatch.kicad_pcb]
2019-03-05 ADD: finalized artwork, first pcbs ordered
    [anotterwatch-B.Adhes.gbr, anotterwatch-B.Cu.gbr, anotterwatch-B.Mask.gbr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]
2019-04-01 added esp32-pico-d4 footprint
2019-04-08 FIX: ESP32 new footprint, fix LED polarity, fix IPS FFC position
    [anotterwatch.kicad_pcb, anotterwatch.sch]
2019-04-08 V1.1 -> Production
    [anotterwatch-B.Adhes.gbr, anotterwatch-B.Cu.gbr, anotterwatch-B.Mask.gbr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]
